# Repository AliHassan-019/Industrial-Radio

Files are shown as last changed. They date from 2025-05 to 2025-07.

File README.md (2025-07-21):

# Industrial Radio

<p align="center">
  <b>Solar-Powered, Wireless, Industrial Current Monitoring System</b><br>
  <i>Non-intrusive, IoT-enabled, and robust for harsh environments</i>
</p>

<p align="center">
  
  
  
</p>

---

## 📑 Table of Contents

- [🚀 Project Overview](#project-overview)
- [✨ Features](#features)
- [🏗️ System Architecture](#system-architecture)
- [🖥️ Block Diagram](#block-diagram)
- [🛠️ Hardware Details](#hardware-details)
  - [Rogowski Coil Interface](#rogowski-coil-interface)
  - [Microcontroller Unit (MCU)](#microcontroller-unit-mcu)
  - [Display Module](#display-module)
  - [Power Management](#power-management)
  - [Communication Modules](#communication-modules)
  - [Additional Components](#additional-components)
- [💾 Firmware Overview](#firmware-overview)
- [🖼️ Mechanical Design](#mechanical-design)
  - [Overall Product Design](#overall-product-design)
  - [2-Layer Mechanical Design (Front and Back Views)](#2-layer-mechanical-design-front-and-back-views)
  - [Internal Design (Device Render/Image)](#internal-design-device-renderimage)
- [🖼️ PCB Design](#pcb-design)
  - [Schematic Diagram](#schematic-diagram)
  - [Top PCB Layer](#top-pcb-layer)
  - [Bottom PCB Layer](#bottom-pcb-layer)
  - [Top 3D View](#top-3d-view)
  - [Bottom 3D View](#bottom-3d-view)
- [Installation & Setup](#installation--setup)
- [Usage](#usage)
- [Troubleshooting](#troubleshooting)
- [Contributing](#contributing)
- [License](#license)

---

## 🚀 Project Overview

**Industrial Radio** is a next-generation, solar-powered, wireless current monitoring system designed for industrial and harsh environments. It uses a Rogowski coil for non-intrusive AC current measurement, an ESP32 microcontroller for advanced processing, and supports both LoRa and GSM for long-range, reliable data transmission. The system is ideal for:

- Remote monitoring of electrical assets
- Predictive maintenance and fault logging
- Industrial automation and energy management
- Smart grid and IoT deployments

**Key Benefits:**
- Non-intrusive, safe installation
- Wireless, long-range communication
- Solar-powered, maintenance-free operation
- Real-time data, alerts, and GPS-based event logging

---

## ✨ Features

- **Non-intrusive AC current measurement** using Rogowski coil
- **Real-time OLED display** (0.96" SSD1306)
- **Solar-powered** with LiPo battery backup
- **Long-range wireless communication** (LoRa, optional GSM)
- **GPS-based location logging**
- **Data logging and system alerts**
- **Environmental and system parameter monitoring**
- **Over-voltage and reverse polarity protection**
- **Modular, robust enclosure and PCB design**
- **Open-source firmware and hardware**

---

## 🏗️ System Architecture

The Industrial Radio system is built from the following main blocks:
- **Rogowski Coil Interface:** Senses AC current and outputs a voltage proportional to the current.
- **MCU (ESP32):** Processes sensor data, manages communication, and controls the system.
- **Display:** Shows real-time data and system status.
- **Power Management:** Solar panel, battery, charging, and voltage regulation.
- **Communication:** LoRa (RFM95) and optional GSM (SIM800L) modules.
- **Additional Components:** GPS, environmental sensors, and protection circuits.

---

## 🖥️ Block Diagram

```text
+-------------------+
|   Rogowski Coil   |
+--------+----------+
         |
         v
+-------------------+
| Integrator Circuit|
+--------+----------+
         |
         v
+-------------------+
|      ESP32 MCU    |
|  +-------------+  |
|  | LoRa Module |  |
|  | GSM Module  |  |
|  | GPS Module  |  |
|  | OLED Display|  |
+--------+----------+
         |
         v
+-------------------+
| Power Management  |
| (Solar, Battery,  |
|  Charging, Boost) |
+-------------------+
```

---

## 🛠️ Hardware Details

### Rogowski Coil Interface
- **Input:** Rogowski coil terminals
- **Integrator Circuit:** RC integrator using op-amp (e.g., TLV2372), resistor, and capacitor
- **Purpose:** Converts di/dt output to voltage proportional to current for accurate AC measurement

### Microcontroller Unit (MCU)
- **Type:** ESP32 (dual-core, WiFi, Bluetooth)
- **Functions:**
  - High-speed signal processing
  - Wireless communication (LoRa/GSM)
  - Data logging, control, and power management

### Display Module
- **Type:** 0.96" OLED (SSD1306)
- **Interface:** I2C
- **Purpose:** Real-time current, system status, alerts, and diagnostics

### Power Management
- **Solar Panel:** 5V, 100–500 mA
- **Battery:** 3.7V LiPo, 1000–1500 mAh
- **Charging Circuit:** TP4056 or CN3791
- **Voltage Regulation:** Boost converter (MT3608) for stable 5V output

### Communication Modules
- **LoRa:** RFM95 (SPI, long-range, low-power)
- **GSM (Optional):** SIM800L (UART, cellular fallback)

### Additional Components
- **GPS:** NEO-6M (UART, location for event logging)
- **Sensors:** Environmental (temperature, humidity, etc.)
- **Protection:** Diodes, fuses, TVS diodes for surge and reverse polarity

---

## 💾 Firmware Overview

- **Language:** C++ (Arduino framework for ESP32)
- **Key Libraries:**
  - Adafruit_SSD1306 (OLED display)
  - LoRa (Sandeep Mistry)
  - TinyGPS++ (GPS)
  - HTTPClient (GSM data upload)
- **Main Functions:**
  - Rogowski coil signal acquisition and integration
  - Real-time display and system status
  - LoRa/GSM data transmission
  - GPS event logging
  - Power management and deep sleep
  - Data logging and alerting

---

## Installation & Setup
1. **Hardware Assembly**
   - Connect Rogowski coil to integrator circuit
   - Connect integrator output to ESP32 ADC
   - Wire OLED, LoRa, GSM, GPS modules to ESP32
   - Connect solar panel, battery, and charging circuit
   - Ensure all protection circuits are in place
2. **Firmware Upload**
   - Install Arduino IDE and ESP32 board support
   - Install required libraries
   - Upload firmware to ESP32
3. **Configuration**
   - Set LoRa frequency and keys
   - Configure GSM APN (if used)
   - Set data logging intervals

---

## Usage
- Power on the device (solar or battery)
- OLED displays real-time current and system status
- Data is transmitted via LoRa/GSM
- GPS logs location for each event
- System enters sleep mode to save power when idle

---

## Troubleshooting
- **No Display**: Check OLED wiring and I2C address
- **No Data Transmission**: Verify LoRa/GSM module connections and configuration
- **No Power**: Check solar panel, battery, and charging circuit
- **Incorrect Readings**: Calibrate integrator circuit and check Rogowski coil orientation

---

## Contributing
Contributions are welcome! Please fork the repository and submit a pull request. For major changes, open an issue first to discuss your ideas.

---

## License
This project is licensed under the MIT License.

---

## 🖼️ Mechanical Design

### Overall Product Design
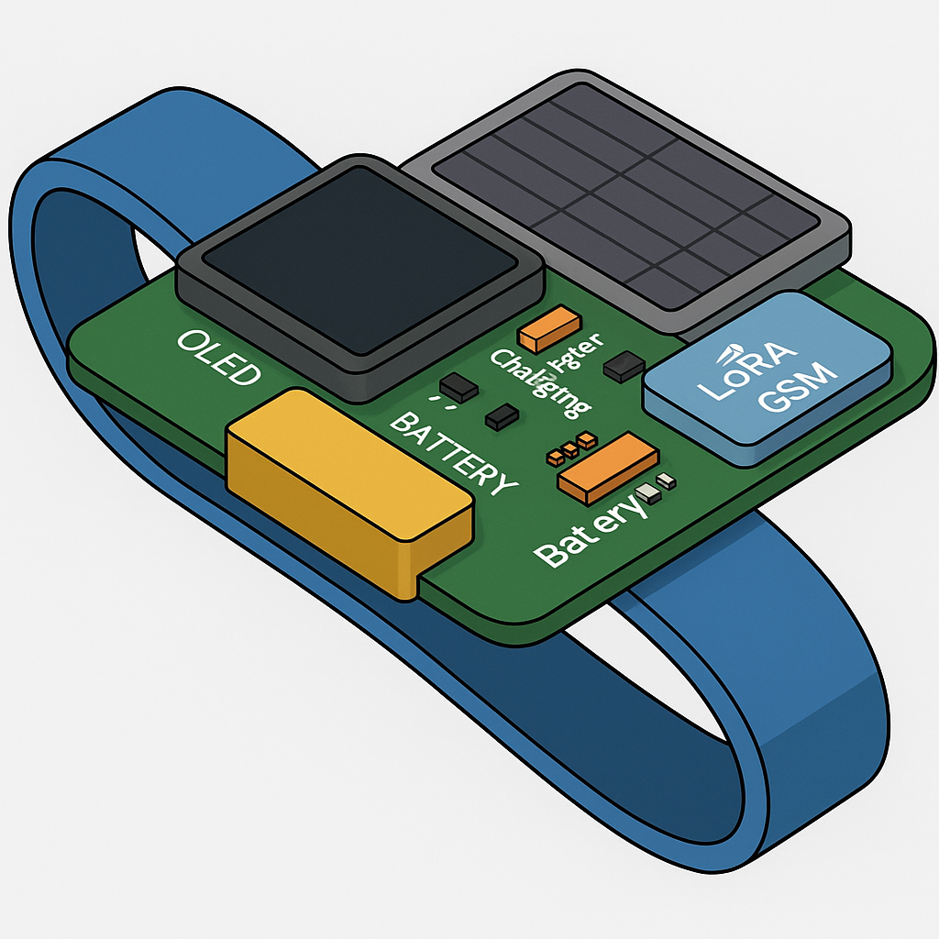
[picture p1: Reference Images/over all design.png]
Overall Product Design


A comprehensive view of the fully assembled Industrial Radio device, showing enclosure, display, and all external features as it will appear in the field.

### 2-Layer Mechanical Design (Front and Back Views)
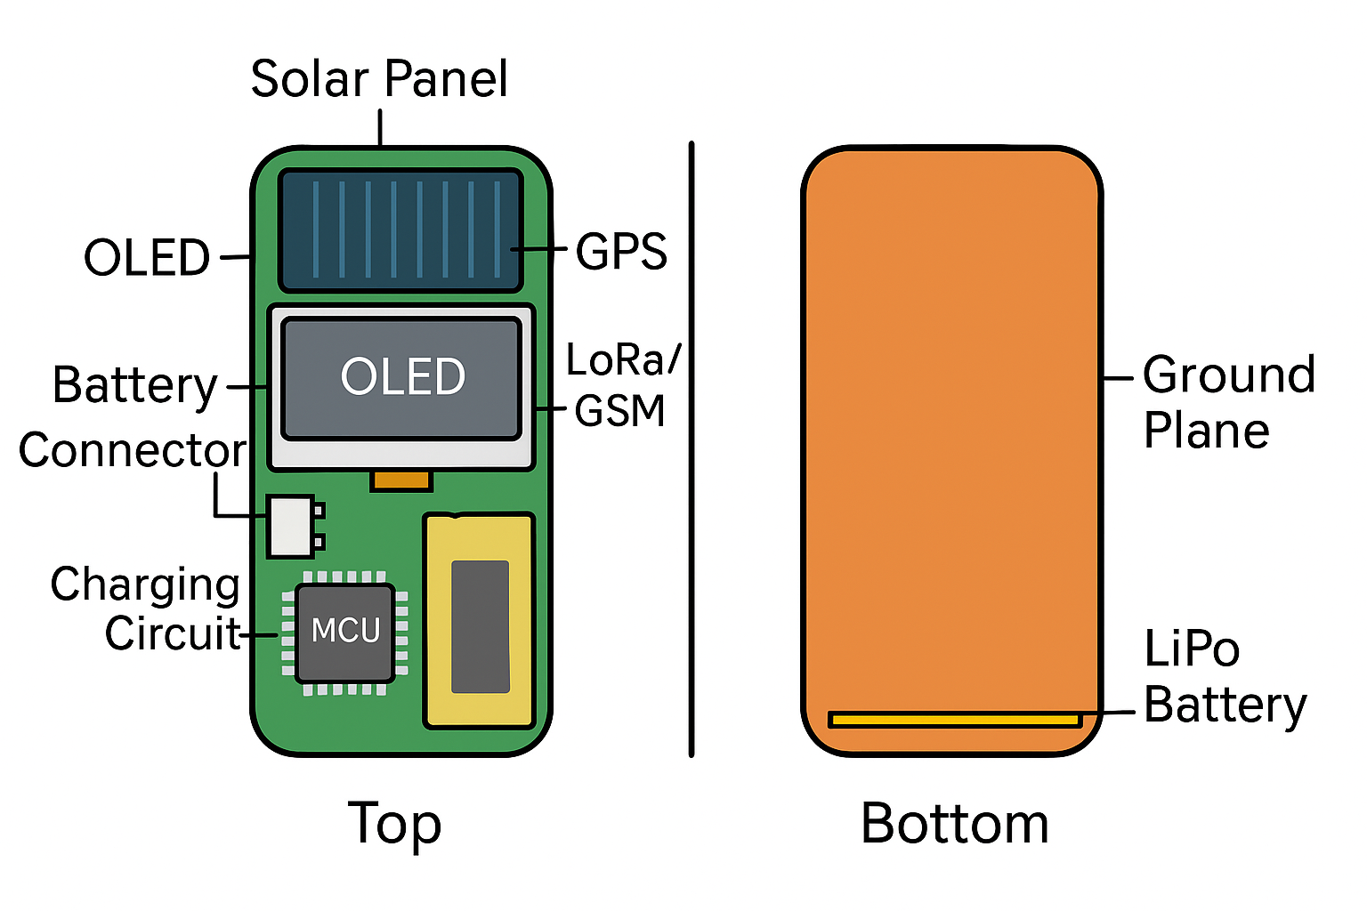
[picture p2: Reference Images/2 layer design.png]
2-Layer Mechanical Design (Front and Back Views)


Front and back enclosure views, showing user interface, display, mounting, and cable entry.

### Internal Design (Device Render/Image)
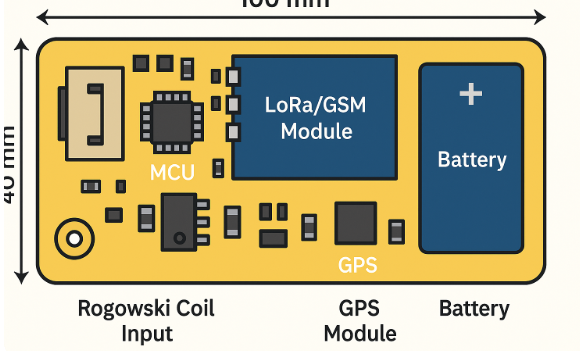
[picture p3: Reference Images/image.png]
Device Render or Photograph


High-quality render or photograph of the device, highlighting the internal build, connectors, and user interface. Useful for understanding internal layout and assembly.

---

## 🖼️ PCB Design

### Schematic Diagram
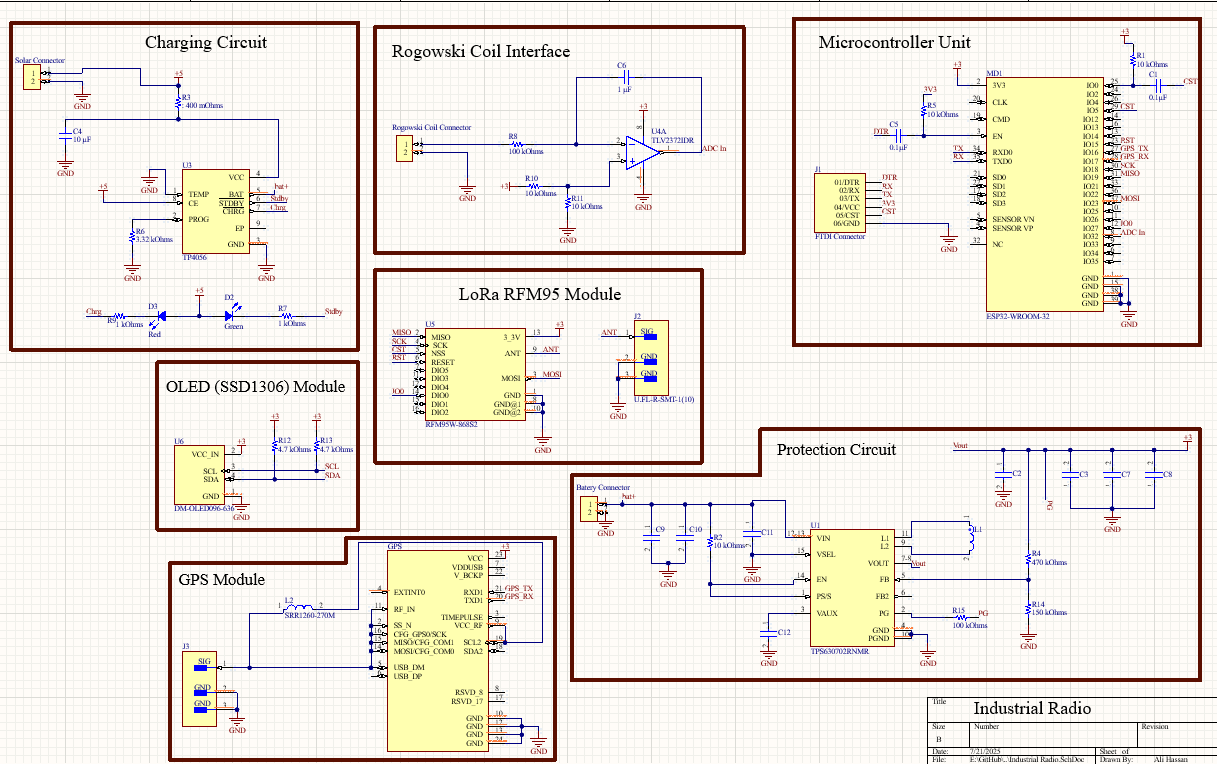
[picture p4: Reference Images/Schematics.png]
Schematic


Complete electrical schematic, showing all interconnections, protections, and signal flow.

### Top PCB Layer
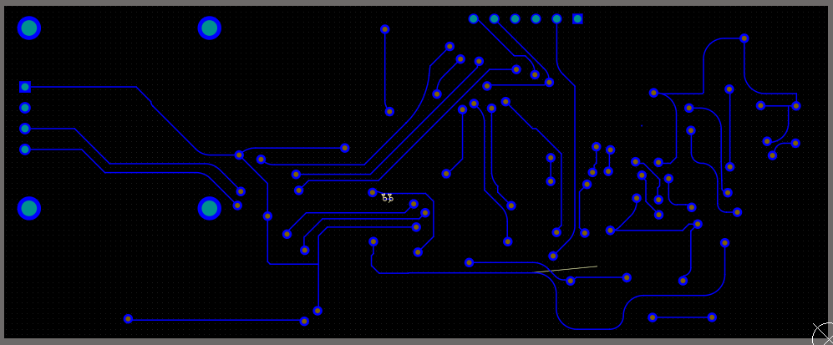
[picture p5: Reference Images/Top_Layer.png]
Top Layer


Shows the top copper layer, component placement, and signal routing. Highlights analog/digital separation and EMI control.

### Bottom PCB Layer
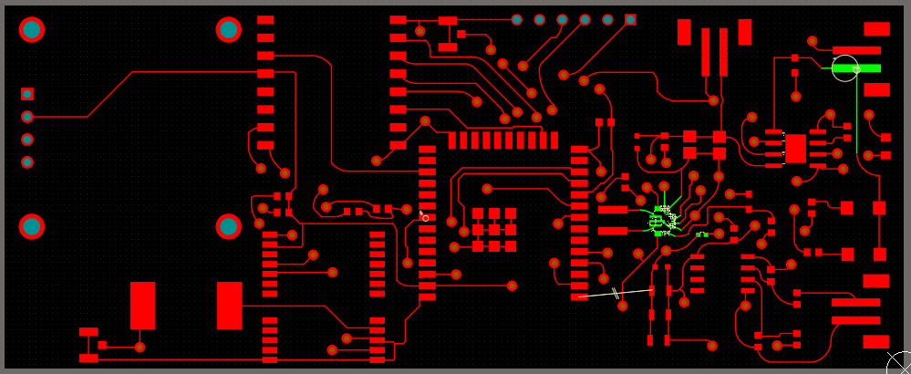
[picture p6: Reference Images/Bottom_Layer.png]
Bottom Layer


Bottom copper layer for ground fills, passives, and mechanical support. Shows return paths and low-priority routing.

### Top 3D View
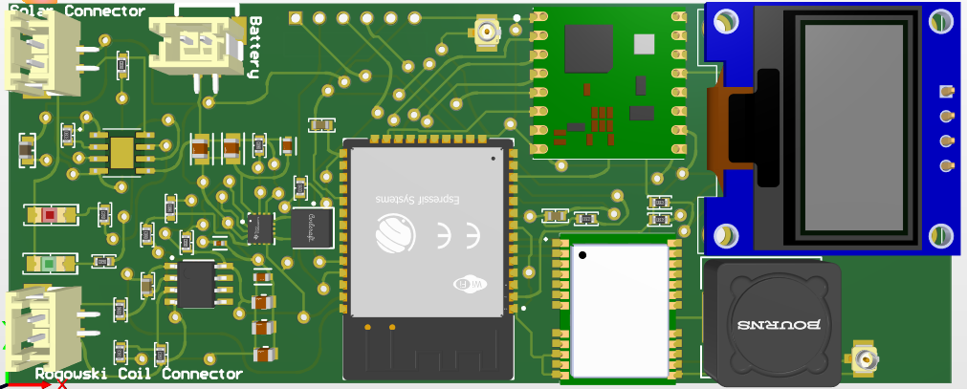
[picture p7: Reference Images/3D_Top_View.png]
Top 3D View


3D render of the assembled PCB from the top. Visualizes component heights, connectors, and fit.

### Bottom 3D View
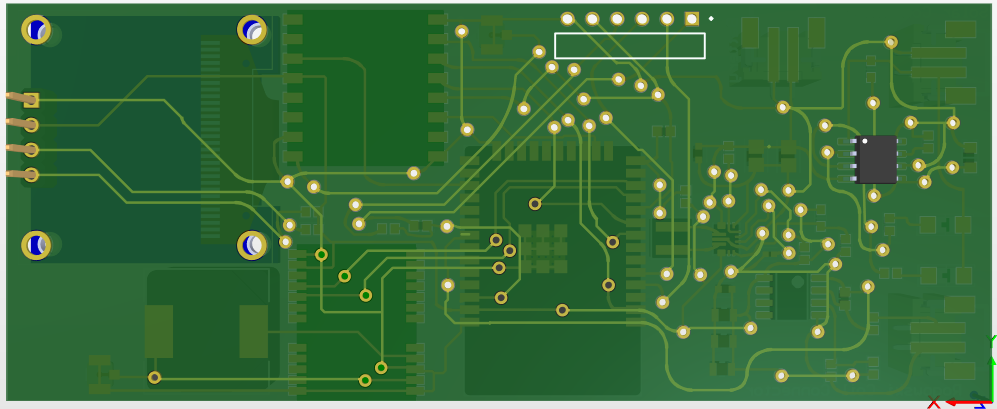
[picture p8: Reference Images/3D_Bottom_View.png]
Bottom 3D View


3D render from the bottom, showing SMD passives, vias, and mounting clearance.

---

## 📝 Mechanical Design Guide

1. **2-Layer Mechanical Design (Front and Back Views):**
   - Familiarize yourself with the device's external appearance. The front view shows the display and user-accessible features; the back view reveals mounting and cable management. Use for installation planning and enclosure fit.
2. **Internal Design (Device Render/Image):**
   - Use this render or photograph to understand the internal layout, wiring, and assembly of the device. This is helpful for troubleshooting, upgrades, and maintenance.
3. **Overall Mechanical Design:**
   - Visualize how all modules fit inside the enclosure. Check for correct positioning, wiring space, and airflow. Useful for presentations and technical documentation.

---

## 🙋‍♂️ Support & Contact

For questions, technical support, or to report issues, please open an issue on the [GitHub repository](https://github.com/AliHassan-019/Industrial-Radio) or contact the project maintainer at [Ali Hassan](mailto:alihassan.pk019@gmail.com).

---

## 🤝 Contributing

Contributions, bug reports, and feature requests are welcome! To contribute:

1. Fork the repository
2. Create a new branch for your feature or fix
3. Commit your changes with clear messages
4. Open a pull request describing your changes

For major changes, please open an issue first to discuss your ideas.

---

## 📄 License

This project is licensed under the MIT License. See the [LICENSE](LICENSE) file for details.

---

<p align="center">
  <b>Thank you for using and supporting Industrial Radio!</b><br>
  <i>Empowering industrial IoT with robust, wireless, and solar-powered monitoring solutions.</i>
</p>

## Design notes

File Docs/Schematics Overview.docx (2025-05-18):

Conceptual Schematic Overview

1. Rogowski Coil Interface:

- Input: Rogowski coil terminals.
- Integrator Circuit: Converts the coil's output (proportional to di/dt) to a voltage proportional to current.
  - Components: Operational amplifier (e.g., TLV2372), resistor (R), and capacitor (C) forming an RC integrator.

2. Microcontroller Unit (MCU):

- Type: ESP32
- Functions:
  - Processes the integrated signal.
  - Handles communication protocols (LoRa/GSM).
  - Manages data logging and system control.

3. Display Module:

- Type: 0.96" OLED (SSD1306).
- Interface: I2C.
- Purpose: Displays real-time data such as current readings, system status, and alerts.

4. Power Management:

- Solar Panel:
  - Specification: 5V, 100–500 mA.
  - Function: Charges the battery and powers the system.
- Battery:
  - Type: 3.7V LiPo, 1000–1500 mAh.
  - Purpose: Provides power during low-light conditions.
- Charging Circuit:
  - Controller: TP4056 or CN3791.
  - Function: Manages charging from the solar panel to the battery.
- Voltage Regulation:
  - Component: Boost converter (e.g., MT3608).
  - Function: Steps up battery voltage to 5V for system components.

5. Communication Modules:

- LoRa Module:
  - Type: RFM95.
  - Interface: SPI.
  - Purpose: Long-range wireless communication.
- GSM Module (Optional):
  - Type: SIM800L.
  - Interface: UART.
  - Purpose: Cellular communication for data transmission.

6. Additional Components:

- GPS Module:
  - Type: NEO-6M.
  - Interface: UART.
  - Purpose: Provides location data for fault logging.
- Sensors:
  - Purpose: Monitor environmental conditions or system parameters.
- Protection Circuits:
  - Components: Diodes, fuses, or TVS diodes.
  - Purpose: Protect against voltage spikes and reverse polarity.

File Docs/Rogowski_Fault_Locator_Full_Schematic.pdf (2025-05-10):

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

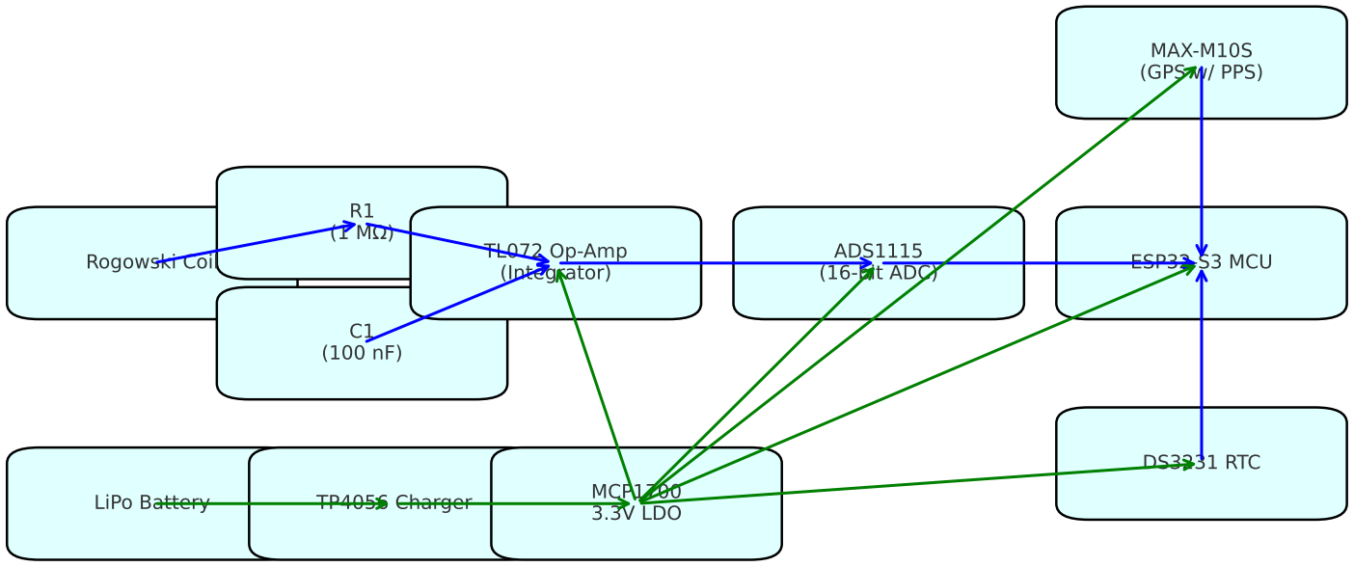
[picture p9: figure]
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

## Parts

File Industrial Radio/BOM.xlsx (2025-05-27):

Comment | Description | Designator | Footprint | LibRef | Quantity | manufacturer | MP
B2B-PH-SM4-TB(LF)(SN) | Connector Header Surface Mount 2 position 0.079 (2.00mm) | Batery Connector, Rogowski Coil Connector, Solar Connector | B2B-PH-SM4-TB(LF)(SN) | B2B-PH-SM4-TB(LF)(SN) | 3 |  | B2B-PH-SM4-TB(LF)(SN)
0.1µF | CAP CER 0.1UF 25V X7R 0603 | C1, C5 | CAP 0603_1608 | 06033C104K4T4A | 2 | AVX Corporation | 06033C104K4T4A
TMK107BBJ106MA-T | Multilayer Ceramic Capacitor 10uF 25V X5R 20% SMD 0603 T/R | C2, C11 | FP-0603-L_1_6_0_2-W_0_8_0-MFG | CMP-14477-005164-2 | 2 | Taiyo Yuden | TMK107BBJ106MA-T
GRM21BC81C226ME44L | Chip Multilayer Ceramic Capacitors for General Purpose, 0805, 22uF, X6S, 22%, 20%, 16V | C3, C7, C8 | FP-GRM21B-0_2-e0_2_0_7-MFG | CMP-06035-012913-1 | 3 | Murata Electronics | GRM21BC81C226ME44L
10 µF | CAP CER 10UF 2.5V X6S 0603 | C4 | MURATA GRM188 0603_1608 | GRM188C80E106ME47D | 1 | Murata Electronics | GRM188C80E106ME47D
1 µF | CAP CER 1UF 6.3V X7R 0603 | C6 | CAP 0603_1608 | C0603X105M9RACAUTO | 1 | KEMET | C0603X105M9RACAUTO
GRM21BC71E106ME11L | Chip Multilayer Ceramic Capacitors for General Purpose, 0805, 10uF, X7S, 22%, 20%, 25V | C9, C10 | FP-GRM21B-0_2-e0_2_0_7-IPC_A | CMP-06035-056773-1 | 2 | Murata Electronics | GRM21BC71E106ME11L
TMK105B7104MV-FR | None | C12 | FP-0402-L_1_0_0_05-W_0_5-IPC_B | CMP-14477-003834-2 | 1 | Taiyo Yuden | TMK105B7104MV-FR
Green | LED GREEN SMD | D2 | LED 1206_3216 GREEN | HSMQ-C380 | 1 | Broadcom Limited | HSMQ-C380
Red | LED RED SMD | D3 | LED 1206_3216 RED | HSMC-C380 | 1 | Broadcom Limited | HSMC-C380
NEO-6M-GPS | GPS Development Tools SparkFun GNSS-RTK Dead Reckoning Breakout - ZED-F9K (Qwiic) | GPS | XCVR_NEO-6M-GPS | NEO-6M-GPS | 1 |  | NEO-6M-GPS
FTDI Connector | Connector Header Through Hole, Right Angle 6 position 0.100 (2.54mm) | J1 | SAMTEC_MTSW-106-09-G-S-375-RA | MTSW-106-09-G-S-375-RA | 1 |  | MTSW-106-09-G-S-375-RA
U.FL-R-SMT-1(10) | CONN U.FL RCPT STR 50 OHM SMD | J2, J3 | FP-U_FL-R-SMT-1_10-MFG | CMP-2000-05152-3 | 2 | Hirose Electric Co Ltd | U.FL-R-SMT-1(10)
XFL4020-152MEC | Inductor Power Shielded Wirewound 1.5uH 20% 100KHz 9.1A 15.8mOhm DCR 1515 Automotive Embossed Plastic T/R | L1 | FP-XFL4020-MFG | CMP-11268-000104-1 | 1 | Coilcraft | XFL4020-152MEC
SRR1260-270M | FIXED IND 27UH 3.6A 45 MOHM SMD | L2 | FP-SRR1260-MFG | CMP-07248-000018-1 | 1 | Bourns | SRR1260-270M
ESP32-WROOM-32 | RX TXRX MOD WIFI SURFACE MOUNT | MD1 | FP-ESP32-WROOM-32-MFG | CMP-194065-000008-1 | 1 | Espressif Systems | ESP32-WROOM-32
10 kOhms | RES SMD 10K OHM 5% 1/10W 0603, RES 10K OHM 0.1% 1/16W 0603 | R1, R2, R5, R10, R11 | RES 0603_1608 | CRCW060310K0JNEA, RNCS0603BKE10K0 | 5 | Vishay Dale, Stackpole Electronics Inc | Stackpole Electronics Inc
=Value | RES 0.4 OHM 1% 1/10W 0603 | R3 | YAGEO RES 0603_1608 | RL0603FR-070R4L | 1 | Yageo | RL0603FR-070R4L
470 kOhms | RES SMD 470K OHM 5% 1/10W 0603 | R4 | YAGEO RES 0603_1608 | AC0603JR-07470KL | 1 | Yageo | AC0603JR-07470KL
3.32 kOhms | RES SMD 3.32K OHM 0.1% 1/5W 0603 | R6 | RES 0603_1608 | ERJ-PB3B3321V | 1 | Panasonic Electronic Components | ERJ-PB3B3321V
1 kOhms | RES SMD 1K OHM 0.1% 1/16W 0603 | R7, R9 | RES 0603_1608 | CPF0603B1K0E | 2 | TE Connectivity Passive Product | CPF0603B1K0E
100 kOhms | RES 100K OHM 0.1% 1/16W 0603 | R8, R15 | RES 0603_1608 | RNCS0603BKE100K | 2 | Stackpole Electronics Inc | RNCS0603BKE100K
4.7 kOhms | RES SMD 4.7K OHM 0.1% 1/10W 0603 | R12, R13 | RES 0603_1608 | ERA-3AEB472V | 2 | Panasonic Electronic Components | ERA-3AEB472V
150 kOhms | RES 150K OHM 1% 1/4W 0603 | R14 | RES 0603_1608 | CRGP0603F150K | 1 | TE Connectivity Passive Product | CRGP0603F150K
TPS630702RNMR | POWER MANAGEMENT | U1 | FP-RNM0015A-MFG | CMP-04918-000193-1 | 1 | Texas Instruments | TPS630702RNMR
TP4056 | Complete single cell Li-Ion battery with a constant current / constant voltage linear charger | U3 | SOP127P600X175-9N | TP4056 | 1 |  | TP4056
TLV2372IDR | 550 uA/Ch, 3 MHz, RRIO Operational Amplifier, 2.7 to 16 V, -40 to 125 degC, 8-pin SOIC (D8), Green (RoHS & no Sb/Br) | U4 | D0008A_M | CMP-0272-02948-3 | 1 | Texas Instruments | TLV2372IDR
RFM95W-868S2 | General ISM < 1GHz LoRaâ„¢ Transceiver Module 868MHz Antenna Not Included Surface Mount | U5 | XCVR_RFM95W-868S2 | RFM95W-868S2 | 1 |  | RFM95W-868S2
DM-OLED096-636 | 0.96â€ 128 X 64 MONOCHROME GRAPHIC OLED DISPLAY MODULE - I2C | U6 | MODULE_DM-OLED096-636 | DM-OLED096-636 | 1 |  | DM-OLED096-636

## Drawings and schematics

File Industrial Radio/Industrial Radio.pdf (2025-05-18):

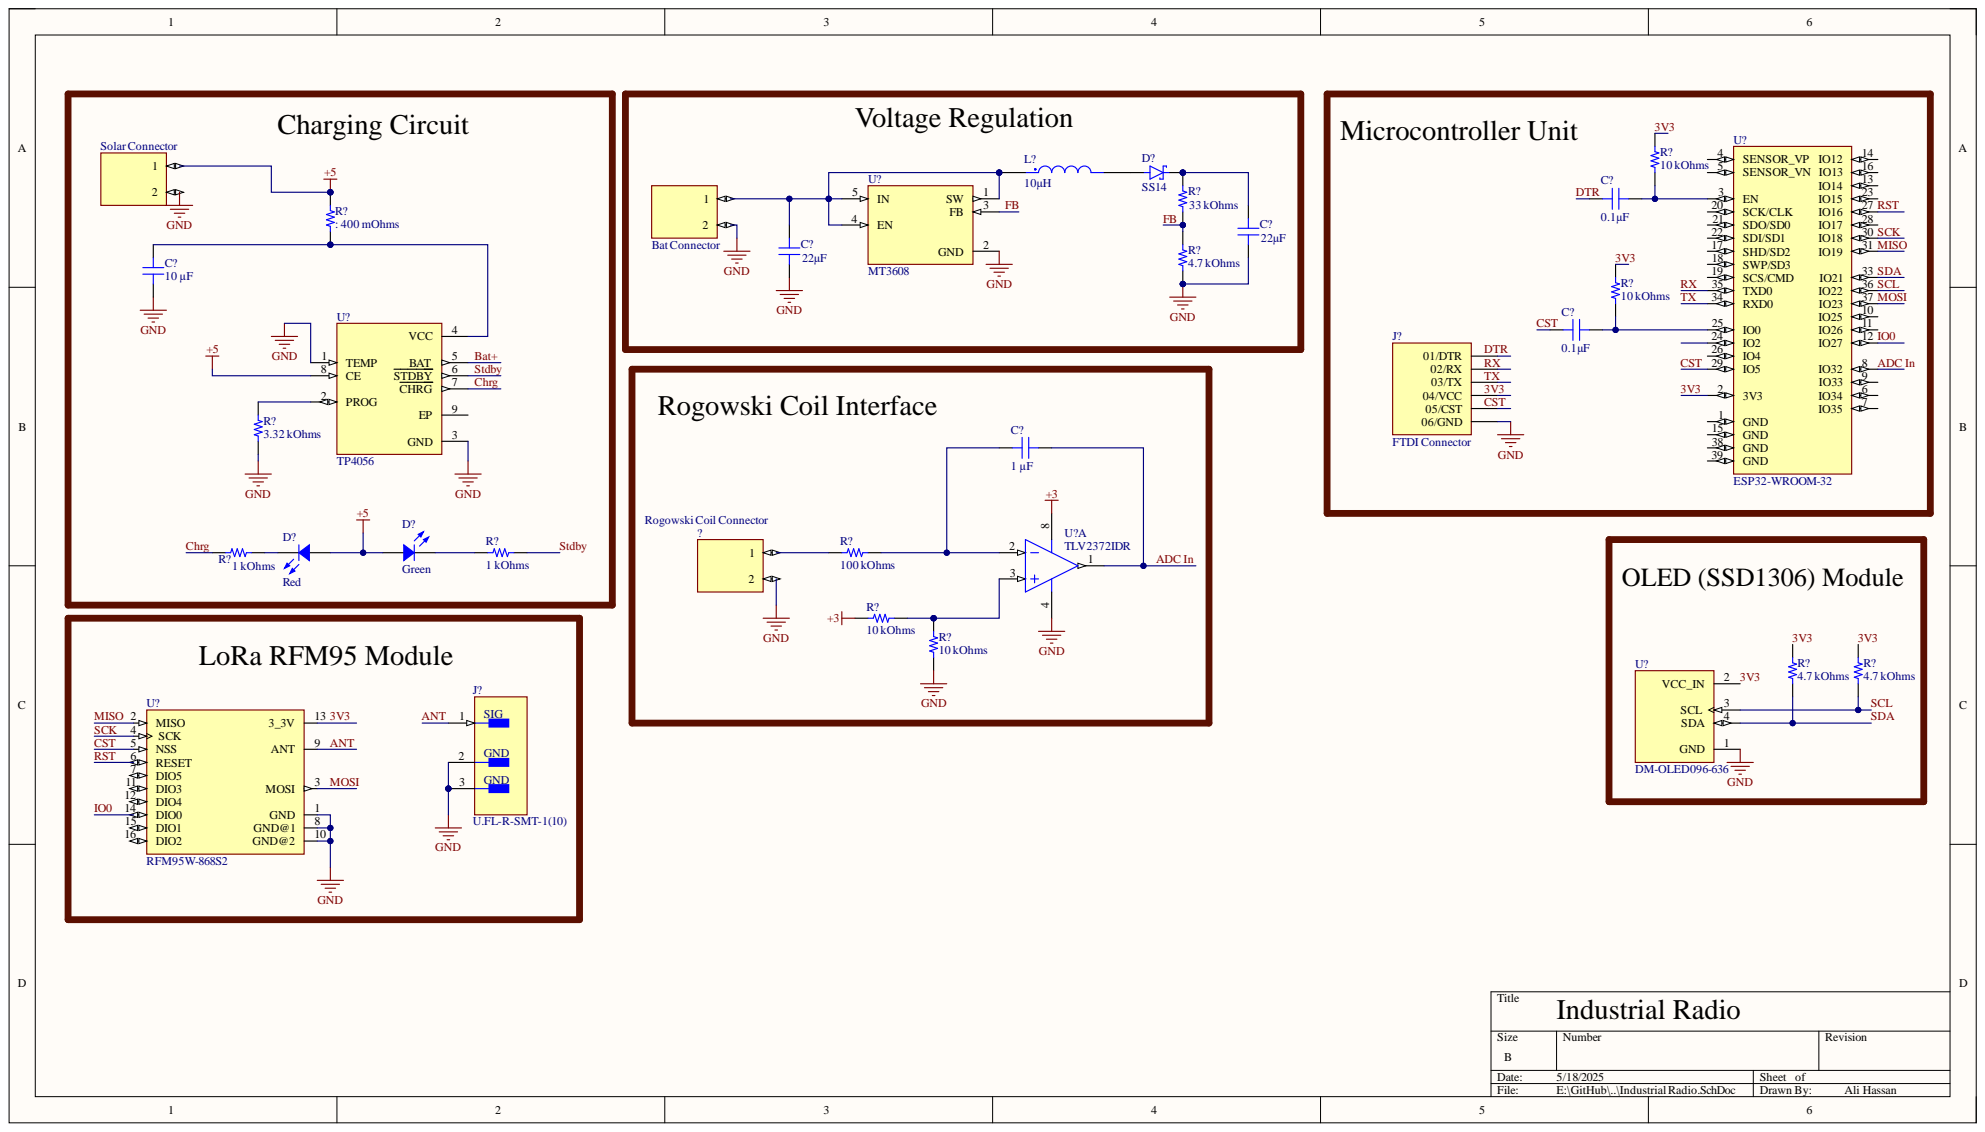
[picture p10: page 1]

SDA SCL MISO SCK MOSI

1 0

B | mb er | Re visi o n

Date : 5/1 8 /2 0 2 5 | S h e et o f
File : E:\GitHu b\. .\In d ustrial Ra dio . S ch D o c | Drawn By : Ali Hassa n

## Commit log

2025-05-11 MPPT Battery Charger
    [Industrial Radio.PrjPcb, Industrial Radio.SchDoc]
2025-05-22 Final Deliverables
    [Industrial Radio.PrjPcb, PCB.PcbDoc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]
2025-05-23 P&P file
    [Pick Place for PCB.csv]
2025-05-27 Final BOM
    [BOM.xlsx]

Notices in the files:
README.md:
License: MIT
